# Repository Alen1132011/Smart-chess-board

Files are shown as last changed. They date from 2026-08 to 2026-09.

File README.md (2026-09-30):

# Smart Chess Board

A physical chess board that can detect the position of chess pieces in real time using Hall effect sensors and provide visual feedback through RGB LEDs.

The project combines custom electronics, firmware and a 3D printed enclosure to create a chess board that can understand what is happening on the board without using mechanical switches.

## Budget & SMT Notes

- **Shipping:** Selected the cheapest available shipping method to Bosnia and Herzegovina ($71.75).
- **SMT Assembly:** I attempted to use Economic SMT Assembly to minimize costs, but JLCPCB automatically forces a switch to **Standard SMT Assembly** when incorporating WS2812B addressable LEDs.
- **Self-Funded Components:** To keep the requested grant minimal, I will personally cover all additional hardware costs (ESP32 controller board, magnets, and 3D printing materials for the enclosure).

## Current Status

The PCB design is complete and the first board is being prepared for production and assembly.

The project is still in development. Some features described below are planned and will be added as the hardware and firmware develop.

Once I assemble and test the first board, I will add more information to this repository, including photos, test results and a much more detailed assembly guide.

## Features

* Real-time piece detection using Hall effect sensors
* 128 Hall effect sensors
* RGB lighting under the chess squares
* Custom PCB designed specifically for the board
* Magnetic chess pieces using neodymium magnets
* Firmware developed for the board
* Planned Stockfish integration
* Planned connection to online chess platforms

## How It Works

Each chess piece has a small magnet in its base. Hall effect sensors placed underneath the board detect the magnetic field and determine whether a piece is present on a square.

The board uses 128 sensors connected through 74HC165 shift registers. This allows the microcontroller to read a large number of sensors without requiring a separate input pin for every sensor.

RGB LEDs are placed underneath the squares and can be used to show things such as possible moves, selected pieces, warnings and other information.

The main idea is to keep the playing surface completely clean while putting all of the electronics underneath it.

## Hardware

The main components currently used in the design are:

* Custom PCB designed in KiCad
* 128x HAL2041SO Hall effect sensors
* 16x 74HC165 shift registers
* SK6812 / WS2812B RGB LEDs
* 100nF capacitors
* 10kΩ and 330Ω resistors
* Chess pieces with neodymium magnets

The exact components and values may change after the first prototype is assembled and tested.

## Repository Structure

```text
CAD/              3D models and enclosure design
Firmware/         Board firmware
PCB/              KiCad PCB design files
Production/       Manufacturing and production files
Smart chess board Additional project files
README.md         Project documentation
```

## Assembly

The first version of the board has not been fully assembled yet, so the complete assembly guide is not available at the moment.

After I build the first board, I will add a detailed guide covering:

* PCB assembly
* Hall sensor placement
* LED installation
* Wiring and power
* Magnet placement in the chess pieces
* Firmware installation
* Initial testing and calibration
* Common problems and fixes

I want the guide to be based on the actual first build rather than documenting steps that have not been tested yet.

## Future Plans

The project is still being developed, and more features will be added after the first working board is finished.

Some of the planned improvements include:

* Stockfish integration
* Better move detection and validation
* More RGB lighting effects
* Online chess integration
* Calibration tools
* Improved enclosure
* More detailed documentation

The first assembled board will be an important milestone because it will show which parts of the current design work as expected and which parts need to be improved.

## Libraries and Tools

* KiCad
* PlatformIO
* FastLED
* Stockfish
  
 ## Project Renders & Schematics

chess board_fixed




## Project Status

PCB design: Complete
CAD design: In progress
Firmware: In progress
First board assembly: Upcoming
Detailed assembly guide: Coming after the first build

This project is being developed step by step. The documentation will be updated as the physical board is built, tested and improved.

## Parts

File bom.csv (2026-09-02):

Item | Description | Quantity | Unit Price (USD) | Total Price (USD) | Link
Bare PCBs | JLCPCB 5pcs Custom Boards (Y11-8263520A) | 1 | 23.50 | 23.50 | https://jlcpcb.com
SMT Stencil | JLCPCB SMT Stainless Steel Stencil (100x100mm) | 1 | 3.07 | 3.07 | https://jlcpcb.com
JLCPCB Shipping | Express shipping for PCB & Stencil to BiH | 1 | 43.38 | 43.38 | https://jlcpcb.com
WS2812B LEDs | LCSC C114586 RGB LEDs (100pcs pack) | 100 | 0.0834 | 8.34 | https://www.lcsc.com/product-detail/C114586.html
A3144 Hall Sensors | LCSC C18221462 SOT-23 Hall Effect Sensors (100pcs pack) | 100 | 0.1159 | 11.59 | https://www.lcsc.com/product-detail/C18221462.html
74HC165 ICs | LCSC C5613 SOIC-16 Shift Registers (10pcs pack) | 10 | 0.1171 | 1.17 | https://www.lcsc.com/product-detail/C5613.html
0805 Capacitors 100nF | LCSC C1591 SMD Capacitors (100pcs pack) | 100 | 0.0108 | 1.08 | https://www.lcsc.com/product-detail/C1591.html
0805 Resistors 10k | LCSC C98220 SMD Resistors (100pcs pack) | 100 | 0.0036 | 0.36 | https://www.lcsc.com/product-detail/C98220.html
LCSC Shipping & Discount | Singapore Post shipping ($12.50) minus discount (-$0.61) | 1 | 11.89 | 11.89 | https://www.lcsc.com
ESP32 DevKit | ESP32-WROOM-32D 30-Pin Board | 1 | 3.50 | 3.50 | https://www.aliexpress.com/item/1005005704190069.html
AliExpress ESP32 Shipping | Shipping for ESP32 board to BiH (11.97 BAM) | 1 | 6.70 | 6.70 | https://www.aliexpress.com/item/1005005704190069.html
Type-C Mini Hot Plate | Mini Hot Plate tool for SMT reflow assembly | 1 | 10.00 | 10.00 | https://www.aliexpress.com/item/1005010119785278.html
Grand Total |  |  |  | 125.19

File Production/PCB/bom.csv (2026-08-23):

Reference | Qty | Value | DNP | Exclude from BOM | Exclude from Board | Footprint | Datasheet
A1 | 1 | Arduino_Nano_Every |  |  |  | Module:Arduino_Nano | https://content.arduino.cc/assets/NANOEveryV3.0_sch.pdf
C1,C2,C3,C4,C5,C6,C7,C8,C9,C10,C11,C12,C13,C14,C15,C16,C17,C18,C19,C20,C21,C22,C23,C24,C25,C26,C27,C28,C29,C30,C31,C32,C33,C34,C35,C36,C37,C38,C39,C40,C41,C42,C43,C44,C45,C46,C47,C48,C49,C50,C51,C52,C53,C54,C55,C56,C57,C58,C59,C60,C61,C62,C63,C64 | 64 | 100nF |  |  |  | Capacitor_SMD:C_0805_2012Metric
D1,D2,D3,D4,D5,D6,D7,D8,D9,D10,D11,D12,D13,D14,D15,D16,D17,D18,D19,D20,D21,D22,D23,D24,D25,D26,D27,D28,D29,D30,D31,D32,D33,D34,D35,D36,D37,D38,D39,D40,D41,D42,D43,D44,D45,D46,D47,D48,D49,D50,D51,D52,D53,D54,D55,D56,D57,D58,D59,D60,D61,D62,D63,D64 | 64 | WS2812B |  |  |  | LED_SMD:LED_WS2812B_PLCC4_5.0x5.0mm_P3.2mm | https://cdn-shop.adafruit.com/datasheets/WS2812B.pdf
R1,R3,R4,R5,R6,R7,R8,R9,R10,R11,R12,R13,R14,R15,R16,R17,R18,R19,R20,R21,R22,R23,R24,R25,R26,R27,R28,R29,R30,R31,R32,R33,R34,R35,R36,R37,R38,R39,R40,R41,R42,R43,R44,R45,R46,R47,R48,R49,R50,R51,R52,R53,R54,R55,R56,R57,R58,R59,R60,R61,R62,R63,R64,R65 | 64 | 10k |  |  |  | Resistor_SMD:R_0805_2012Metric
R2 | 1 | 330Ω |  |  |  | Resistor_SMD:R_0805_2012Metric
U1,U3,U4,U5,U6,U7,U8,U9,U11,U12,U13,U14,U15,U16,U17,U18,U20,U21,U22,U23,U24,U25,U26,U27,U29,U30,U31,U32,U33,U34,U35,U36,U38,U39,U40,U41,U42,U43,U44,U45,U47,U48,U49,U50,U51,U52,U53,U54,U56,U57,U58,U59,U60,U61,U62,U63,U65,U66,U67,U68,U69,U70,U71,U72 | 64 | A1104xLH |  |  |  | Package_TO_SOT_SMD:SOT-23W | https://www.allegromicro.com/-/media/files/datasheets/a110x-datasheet.ashx
U2,U10,U19,U28,U37,U46,U55,U64 | 8 | 74HC165 |  |  |  | Package_TO_SOT_SMD:SOT-23W | https://assets.nexperia.com/documents/data-sheet/74HC_HCT165.pdf

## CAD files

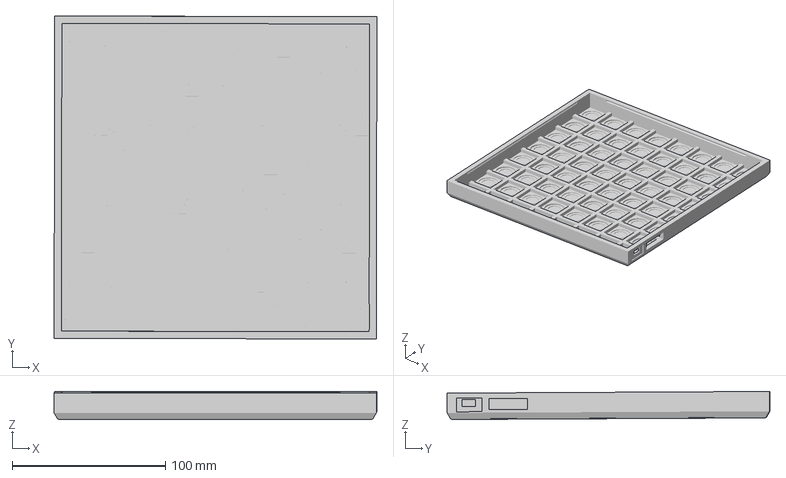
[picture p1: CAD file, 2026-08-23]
Smart chess board/CAD/Chess Board.3mf
210.7 x 210.8 x 18.3 mm

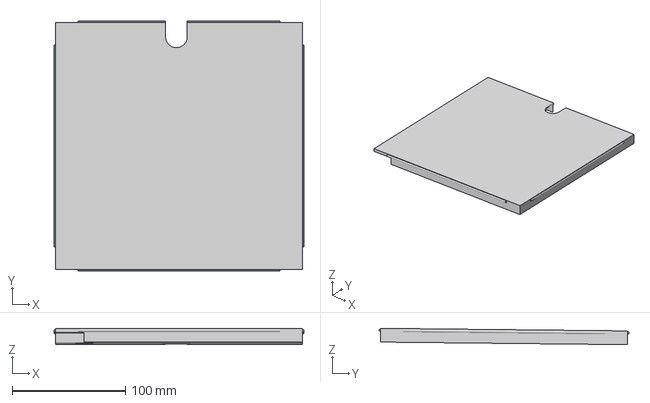
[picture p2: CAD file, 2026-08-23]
Smart chess board/CAD/LID.3mf
220.5 x 220.5 x 14.4 mm

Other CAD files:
CAD/Chess board and lid_.step
PCB/chessboard.step
Production/CAD/Chess board and lid_.step
Smart chess board/PCB/chessboard.step

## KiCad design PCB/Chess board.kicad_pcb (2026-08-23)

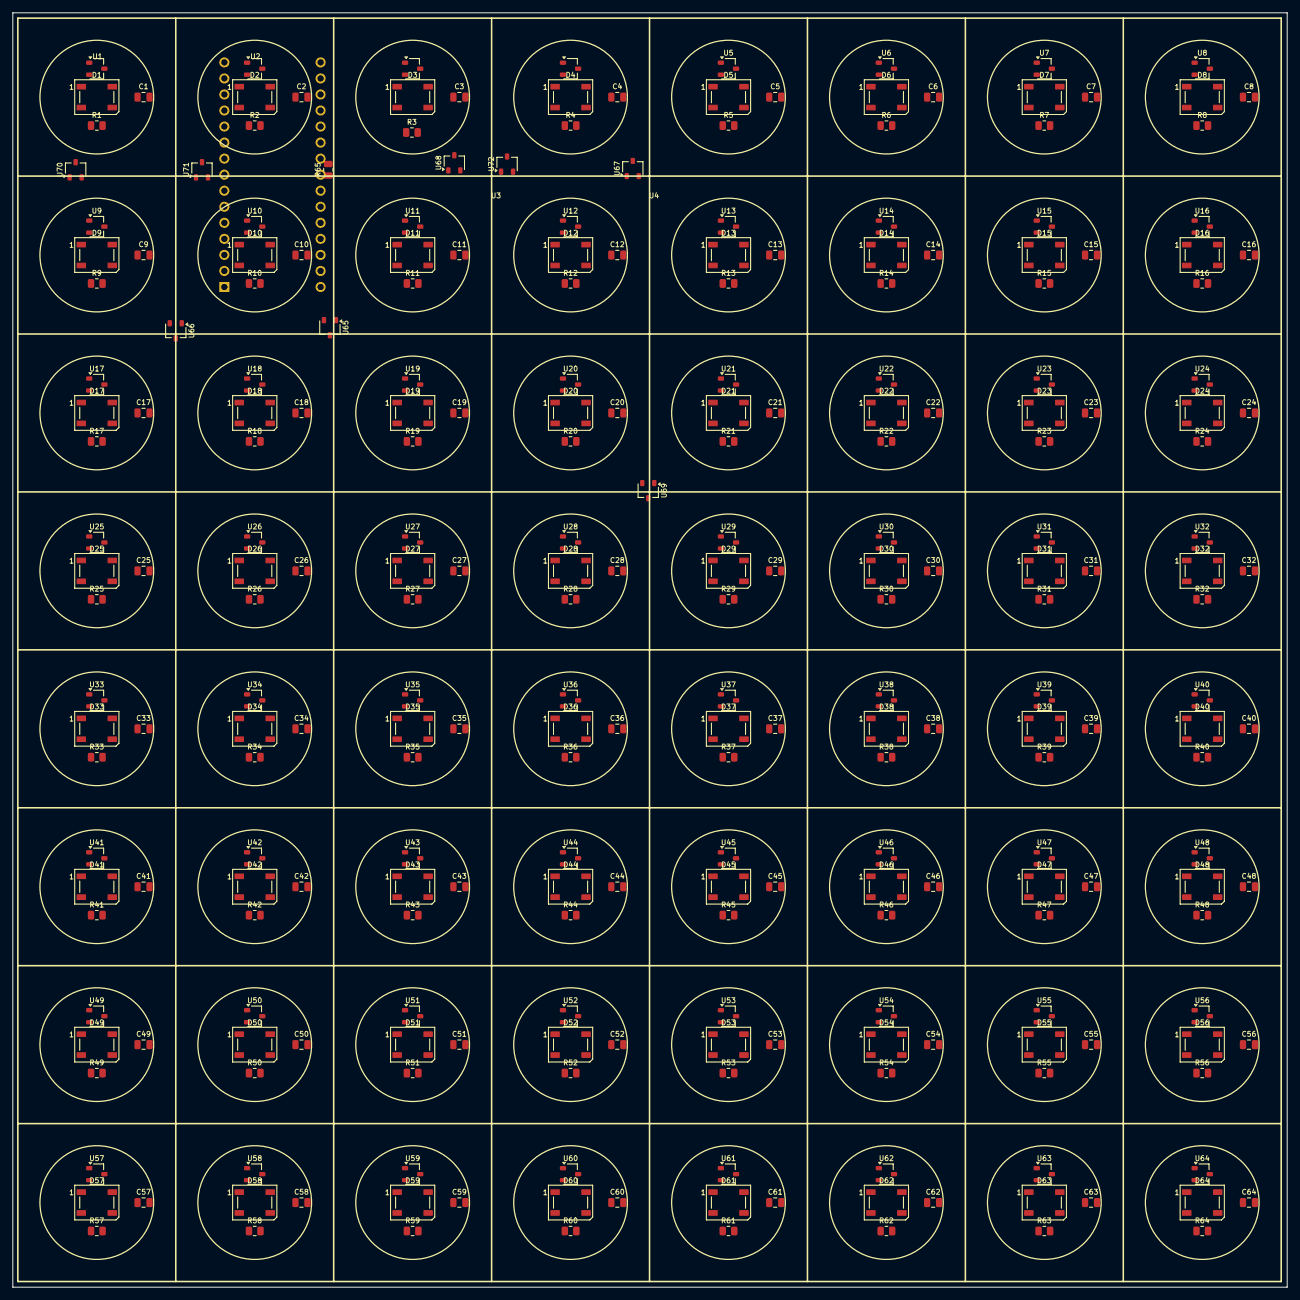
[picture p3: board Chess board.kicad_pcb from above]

Board: 2 copper layers, 201.8 x 201.8 mm, 266 parts (1 on the bottom side), 132 nets, no tracks yet.

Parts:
A1: Arduino_Nano_Every; Arduino_Nano
C1, C2, C3, C4, C5, C6, C7, C8, C9, C10, C11, C12, C13, C14, C15, C16, C17, C18, C19, C20, C21, C22, C23, C24, C25, C26, C27, C28, C29, C30, C31, C32, C33, C34, C35, C36, C37, C38, C39, C40, C41, C42, C43, C44, C45, C46, C47, C48, C49, C50, C51, C52, C53, C54, C55, C56, C57, C58, C59, C60, C61, C62, C63, C64: 100nF; C_0805_2012Metric
D1, D2, D3, D4, D5, D6, D7, D8, D9, D10, D11, D12, D13, D14, D15, D16, D17, D18, D19, D20, D21, D22, D23, D24, D25, D26, D27, D28, D29, D30, D31, D32, D33, D34, D35, D36, D37, D38, D39, D40, D41, D42, D43, D44, D45, D46, D47, D48, D49, D50, D51, D52, D53, D54, D55, D56, D57, D58, D59, D60, D61, D62, D63, D64: WS2812B; LED_WS2812B_PLCC4_5.0x5.0mm_P3.2mm
R1, R3, R4, R5, R6, R7, R8, R9, R10, R11, R12, R13, R14, R15, R16, R17, R18, R19, R20, R21, R22, R23, R24, R25, R26, R27, R28, R29, R30, R31, R32, R33, R34, R35, R36, R37, R38, R39, R40, R41, R42, R43, R44, R45, R46, R47, R48, R49, R50, R51, R52, R53, R54, R55, R56, R57, R58, R59, R60, R61, R62, R63, R64, R65: 10k; R_0805_2012Metric
R2: 330Ω; R_0805_2012Metric
U1, U3, U4, U5, U6, U7, U8, U9, U11, U12, U13, U14, U15, U16, U17, U18, U20, U21, U22, U23, U24, U25, U26, U27, U29, U30, U31, U32, U33, U34, U35, U36, U38, U39, U40, U41, U42, U43, U44, U45, U47, U48, U49, U50, U51, U52, U53, U54, U56, U57, U58, U59, U60, U61, U62, U63, U65, U66, U67, U68, U69, U70, U71, U72: A1104xLH; SOT-23W
U2, U10, U19, U28, U37, U46, U55, U64: 74HC165; SOT-23W

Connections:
+5V: A1.27 (+5V), C1.2, C2.2, C3.2, C4.2, C5.2, C6.2, C7.2, C8.2, C9.2, C10.2, C11.2, C12.2, C13.2, C14.2, C15.2, C16.2, C17.2, C18.2, C19.2, C20.2, C21.2, C22.2, C23.2, C24.2, C25.2, C26.2, C27.2, C28.2, C29.2, C30.2, C31.2, C32.2, C33.2, C34.2, C35.2, C36.2, C37.2, C38.2, C39.2, C40.2, C41.2, C42.2, C43.2, C44.2, C45.2, C46.2, C47.2, C48.2, C49.2, C50.2, C51.2, C52.2, C53.2, C54.2, C55.2, C56.2, C57.2, C58.2, C59.2, C60.2, C61.2, C62.2, C63.2, C64.2, D1.1 (VDD), D2.1 (VDD), D3.1 (VDD), D4.1 (VDD), D5.1 (VDD), D6.1 (VDD), D7.1 (VDD), D8.1 (VDD), D9.1 (VDD), D10.1 (VDD), D11.1 (VDD), D12.1 (VDD), D13.1 (VDD), D14.1 (VDD), D15.1 (VDD), D16.1 (VDD), D17.1 (VDD), D18.1 (VDD), D19.1 (VDD), D20.1 (VDD), D21.1 (VDD), D22.1 (VDD), D23.1 (VDD), D24.1 (VDD), D25.1 (VDD), D26.1 (VDD), D27.1 (VDD), D28.1 (VDD), D29.1 (VDD), D30.1 (VDD), D31.1 (VDD), D32.1 (VDD), D33.1 (VDD), D34.1 (VDD), D35.1 (VDD), D36.1 (VDD), D37.1 (VDD), D38.1 (VDD), D39.1 (VDD), D40.1 (VDD), D41.1 (VDD), D42.1 (VDD), D43.1 (VDD), D44.1 (VDD), D45.1 (VDD), D46.1 (VDD), D47.1 (VDD), D48.1 (VDD), D49.1 (VDD), D50.1 (VDD), D51.1 (VDD), D52.1 (VDD), D53.1 (VDD), D54.1 (VDD), D55.1 (VDD), D56.1 (VDD), D57.1 (VDD), D58.1 (VDD), D59.1 (VDD), D60.1 (VDD), D61.1 (VDD), D62.1 (VDD), D63.1 (VDD), D64.1 (VDD), R1.1, R3.1, R4.1, R5.1, R6.1, R7.1, R8.1, R9.1, R10.1, R11.1, R12.1, R13.1, R14.1, R15.1, R16.1, R17.1, R18.1, R19.1, R20.1, R21.1, R22.1, R23.1, R24.1, R25.1, R26.1, R27.1, R28.1, R29.1, R30.1, R31.1, R32.1, R33.1, R34.1, R35.1, R36.1, R37.1, R38.1, R39.1, R40.1, R41.1, R42.1, R43.1, R44.1, R45.1, R46.1, R47.1, R48.1, R49.1, R50.1, R51.1, R52.1, R53.1, R54.1, R55.1, R56.1, R57.1, R58.1, R59.1, R60.1, R61.1, R62.1, R63.1, R64.1, R65.1, U1.1 (V_{CC}), U3.1 (V_{CC}), U4.1 (V_{CC}), U5.1 (V_{CC}), U6.1 (V_{CC}), U7.1 (V_{CC}), U8.1 (V_{CC}), U9.1 (V_{CC}), U11.1 (V_{CC}), U12.1 (V_{CC}), U13.1 (V_{CC}), U14.1 (V_{CC}), U15.1 (V_{CC}), U16.1 (V_{CC}), U17.1 (V_{CC}), U18.1 (V_{CC}), U20.1 (V_{CC}), U21.1 (V_{CC}), U22.1 (V_{CC}), U23.1 (V_{CC}), U24.1 (V_{CC}), U25.1 (V_{CC}), U26.1 (V_{CC}), U27.1 (V_{CC}), U29.1 (V_{CC}), U30.1 (V_{CC}), U31.1 (V_{CC}), U32.1 (V_{CC}), U33.1 (V_{CC}), U34.1 (V_{CC}), U35.1 (V_{CC}), U36.1 (V_{CC}), U38.1 (V_{CC}), U39.1 (V_{CC}), U40.1 (V_{CC}), U41.1 (V_{CC}), U42.1 (V_{CC}), U43.1 (V_{CC}), U44.1 (V_{CC}), U45.1 (V_{CC}), U47.1 (V_{CC}), U48.1 (V_{CC}), U49.1 (V_{CC}), U50.1 (V_{CC}), U51.1 (V_{CC}), U52.1 (V_{CC}), U53.1 (V_{CC}), U54.1 (V_{CC}), U56.1 (V_{CC}), U57.1 (V_{CC}), U58.1 (V_{CC}), U59.1 (V_{CC}), U60.1 (V_{CC}), U61.1 (V_{CC}), U62.1 (V_{CC}), U63.1 (V_{CC}), U65.1 (V_{CC}), U66.1 (V_{CC}), U67.1 (V_{CC}), U68.1 (V_{CC}), U69.1 (V_{CC}), U70.1 (V_{CC}), U71.1 (V_{CC}), U72.1 (V_{CC})
/S0: R1.2, U1.2 (V_{OUT})
/S1: R3.2, U3.2 (V_{OUT})
/S2: R4.2, U4.2 (V_{OUT})
/S3: R5.2, U5.2 (V_{OUT})
/S4: R6.2, U2.3 (D4), U6.2 (V_{OUT})
/S5: R7.2, U7.2 (V_{OUT})
/S6: R8.2, U8.2 (V_{OUT})
/S7: R9.2, U9.2 (V_{OUT})
/S8: R11.2, U11.2 (V_{OUT})
/S9: R10.2, U12.2 (V_{OUT})
/S10: R12.2, U13.2 (V_{OUT})
/S11: R13.2, U14.2 (V_{OUT})
/S12: R14.2, U10.3 (D4), U15.2 (V_{OUT})
/S13: R15.2, U16.2 (V_{OUT})
/S14: R16.2, U17.2 (V_{OUT})
/S15: R17.2, U18.2 (V_{OUT})
/S16: R18.2, U20.2 (V_{OUT})
/S17: R19.2, U21.2 (V_{OUT})
/S18: R20.2, U22.2 (V_{OUT})
/S19: R21.2, U23.2 (V_{OUT})
/S20: R22.2, U19.3 (D4), U24.2 (V_{OUT})
/S21: R23.2, U25.2 (V_{OUT})
/S22: R24.2, U26.2 (V_{OUT})
/S23: R25.2, U27.2 (V_{OUT})
/S24: R26.2, U29.2 (V_{OUT})
/S25: R27.2, U30.2 (V_{OUT})
/S26: R28.2, U31.2 (V_{OUT})
/S27: R29.2, U32.2 (V_{OUT})
/S28: R30.2, U28.3 (D4), U33.2 (V_{OUT})
/S29: R31.2, U34.2 (V_{OUT})
/S30: R32.2, U35.2 (V_{OUT})
/S31: R33.2, U36.2 (V_{OUT})
/S32: R34.2, U38.2 (V_{OUT})
/S33: R35.2, U39.2 (V_{OUT})
/S34: R36.2, U40.2 (V_{OUT})
/S35: R37.2, U41.2 (V_{OUT})
/S36: R38.2, U37.3 (D4), U42.2 (V_{OUT})
/S37: R39.2, U43.2 (V_{OUT})
/S38: R40.2, U44.2 (V_{OUT})
/S39: R41.2, U45.2 (V_{OUT})
/S40: R42.2, U47.2 (V_{OUT})
/S41: R43.2, U48.2 (V_{OUT})
/S42: R44.2, U49.2 (V_{OUT})
/S43: R45.2, U50.2 (V_{OUT})
/S44: R46.2, U46.3 (D4), U51.2 (V_{OUT})
/S45: R47.2, U52.2 (V_{OUT})
/S46: R48.2, U53.2 (V_{OUT})
/S47: R49.2, U54.2 (V_{OUT})
/S48: R50.2, U56.2 (V_{OUT})
/S49: R51.2, U57.2 (V_{OUT})
/S50: R52.2, U58.2 (V_{OUT})
/S51: R53.2, U59.2 (V_{OUT})
/S52: R54.2, U55.3 (D4), U60.2 (V_{OUT})
/S53: R55.2, U61.2 (V_{OUT})
/S54: R56.2, U62.2 (V_{OUT})
/S55: R57.2, U63.2 (V_{OUT})
/S56: R58.2, U65.2 (V_{OUT})
/S57: R59.2, U66.2 (V_{OUT})
/S58: R60.2, U67.2 (V_{OUT})
/S59: R61.2, U68.2 (V_{OUT})
/S60: R62.2, U64.3 (D4), U69.2 (V_{OUT})
/S61: R63.2, U70.2 (V_{OUT})
/S62: R64.2, U71.2 (V_{OUT})
/S63: R65.2, U72.2 (V_{OUT})
GND: A1.4 (GND), A1.6 (D3), A1.29 (GND), C1.1, C2.1, C3.1, C4.1, C5.1, C6.1, C7.1, C8.1, C9.1, C10.1, C11.1, C12.1, C13.1, C14.1, C15.1, C16.1, C17.1, C18.1, C19.1, C20.1, C21.1, C22.1, C23.1, C24.1, C25.1, C26.1, C27.1, C28.1, C29.1, C30.1, C31.1, C32.1, C33.1, C34.1, C35.1, C36.1, C37.1, C38.1, C39.1, C40.1, C41.1, C42.1, C43.1, C44.1, C45.1, C46.1, C47.1, C48.1, C49.1, C50.1, C51.1, C52.1, C53.1, C54.1, C55.1, C56.1, C57.1, C58.1, C59.1, C60.1, C61.1, C62.1, C63.1, C64.1, D1.3 (VSS), D2.3 (VSS), D3.3 (VSS), D4.3 (VSS), D5.3 (VSS), D6.3 (VSS), D7.3 (VSS), D8.3 (VSS), D9.3 (VSS), D10.3 (VSS), D11.3 (VSS), D12.3 (VSS), D13.3 (VSS), D14.3 (VSS), D15.3 (VSS), D16.3 (VSS), D17.3 (VSS), D18.3 (VSS), D19.3 (VSS), D20.3 (VSS), D21.3 (VSS), D22.3 (VSS), D23.3 (VSS), D24.3 (VSS), D25.3 (VSS), D26.3 (VSS), D27.3 (VSS), D28.3 (VSS), D29.3 (VSS), D30.3 (VSS), D31.3 (VSS), D32.3 (VSS), D33.3 (VSS), D34.3 (VSS), D35.3 (VSS), D36.3 (VSS), D37.3 (VSS), D38.3 (VSS), D39.3 (VSS), D40.3 (VSS), D41.3 (VSS), D42.3 (VSS), D43.3 (VSS), D44.3 (VSS), D45.3 (VSS), D46.3 (VSS), D47.3 (VSS), D48.3 (VSS), D49.3 (VSS), D50.3 (VSS), D51.3 (VSS), D52.3 (VSS), D53.3 (VSS), D54.3 (VSS), D55.3 (VSS), D56.3 (VSS), D57.3 (VSS), D58.3 (VSS), D59.3 (VSS), D60.3 (VSS), D61.3 (VSS), D62.3 (VSS), D63.3 (VSS), D64.2 (DOUT), D64.3 (VSS), U1.3 (GND), U2.1 (~PL), U3.3 (GND), U4.3 (GND), U5.3 (GND), U6.3 (GND), U7.3 (GND), U8.3 (GND), U9.3 (GND), U10.1 (~PL), U11.3 (GND), U12.3 (GND), U13.3 (GND), U14.3 (GND), U15.3 (GND), U16.3 (GND), U17.3 (GND), U18.3 (GND), U19.1 (~PL), U20.3 (GND), U21.3 (GND), U22.3 (GND), U23.3 (GND), U24.3 (GND), U25.3 (GND), U26.3 (GND), U27.3 (GND), U28.1 (~PL), U29.3 (GND), U30.3 (GND), U31.3 (GND), U32.3 (GND), U33.3 (GND), U34.3 (GND), U35.3 (GND), U36.3 (GND), U37.1 (~PL), U38.3 (GND), U39.3 (GND), U40.3 (GND), U41.3 (GND), U42.3 (GND), U43.3 (GND), U44.3 (GND), U45.3 (GND), U46.1 (~PL), U47.3 (GND), U48.3 (GND), U49.3 (GND), U50.3 (GND), U51.3 (GND), U52.3 (GND), U53.3 (GND), U54.3 (GND), U55.1 (~PL), U56.3 (GND), U57.3 (GND), U58.3 (GND), U59.3 (GND), U60.3 (GND), U61.3 (GND), U62.3 (GND), U63.3 (GND), U64.1 (~PL), U65.3 (GND), U66.3 (GND), U67.3 (GND), U68.3 (GND), U69.3 (GND), U70.3 (GND), U71.3 (GND), U72.3 (GND)
unnamed: A1.5 (D2), U2.2 (CP), U10.2 (CP), U19.2 (CP), U28.2 (CP), U37.2 (CP), U46.2 (CP), U55.2 (CP), U64.2 (CP)
unnamed: A1.9 (D6), R2.2
unnamed: D1.4 (DIN), R2.1
unnamed: D1.2 (DOUT), D2.4 (DIN)
unnamed: D2.2 (DOUT), D3.4 (DIN)
unnamed: D3.2 (DOUT), D4.4 (DIN)
unnamed: D4.2 (DOUT), D5.4 (DIN)
unnamed: D5.2 (DOUT), D6.4 (DIN)
unnamed: D6.2 (DOUT), D7.4 (DIN)
unnamed: D7.2 (DOUT), D8.4 (DIN)
unnamed: D8.2 (DOUT), D9.4 (DIN)
unnamed: D9.2 (DOUT), D10.4 (DIN)
unnamed: D10.2 (DOUT), D11.4 (DIN)
unnamed: D11.2 (DOUT), D12.4 (DIN)
unnamed: D12.2 (DOUT), D13.4 (DIN)
unnamed: D13.2 (DOUT), D14.4 (DIN)
unnamed: D14.2 (DOUT), D15.4 (DIN)
unnamed: D15.2 (DOUT), D16.4 (DIN)
unnamed: D16.2 (DOUT), D17.4 (DIN)
unnamed: D17.2 (DOUT), D18.4 (DIN)
unnamed: D18.2 (DOUT), D19.4 (DIN)
unnamed: D19.2 (DOUT), D20.4 (DIN)
unnamed: D20.2 (DOUT), D21.4 (DIN)
unnamed: D21.2 (DOUT), D22.4 (DIN)
unnamed: D22.2 (DOUT), D23.4 (DIN)
unnamed: D23.2 (DOUT), D24.4 (DIN)
unnamed: D24.2 (DOUT), D25.4 (DIN)
unnamed: D25.2 (DOUT), D26.4 (DIN)
unnamed: D26.2 (DOUT), D27.4 (DIN)
unnamed: D27.2 (DOUT), D28.4 (DIN)
unnamed: D28.2 (DOUT), D29.4 (DIN)
unnamed: D29.2 (DOUT), D30.4 (DIN)
unnamed: D30.2 (DOUT), D31.4 (DIN)
unnamed: D31.2 (DOUT), D32.4 (DIN)
unnamed: D32.2 (DOUT), D33.4 (DIN)
unnamed: D33.2 (DOUT), D34.4 (DIN)
unnamed: D34.2 (DOUT), D35.4 (DIN)
unnamed: D35.2 (DOUT), D36.4 (DIN)
unnamed: D36.2 (DOUT), D37.4 (DIN)
unnamed: D37.2 (DOUT), D38.4 (DIN)
unnamed: D38.2 (DOUT), D39.4 (DIN)
unnamed: D39.2 (DOUT), D40.4 (DIN)
unnamed: D40.2 (DOUT), D41.4 (DIN)
unnamed: D41.2 (DOUT), D42.4 (DIN)
unnamed: D42.2 (DOUT), D43.4 (DIN)
unnamed: D43.2 (DOUT), D44.4 (DIN)
unnamed: D44.2 (DOUT), D45.4 (DIN)
unnamed: D45.2 (DOUT), D46.4 (DIN)
unnamed: D46.2 (DOUT), D47.4 (DIN)
unnamed: D47.2 (DOUT), D48.4 (DIN)
unnamed: D48.2 (DOUT), D49.4 (DIN)
unnamed: D49.2 (DOUT), D50.4 (DIN)
unnamed: D50.2 (DOUT), D51.4 (DIN)
unnamed: D51.2 (DOUT), D52.4 (DIN)
unnamed: D52.2 (DOUT), D53.4 (DIN)
unnamed: D53.2 (DOUT), D54.4 (DIN)
unnamed: D54.2 (DOUT), D55.4 (DIN)
unnamed: D55.2 (DOUT), D56.4 (DIN)
unnamed: D56.2 (DOUT), D57.4 (DIN)
unnamed: D57.2 (DOUT), D58.4 (DIN)
unnamed: D58.2 (DOUT), D59.4 (DIN)
unnamed: D59.2 (DOUT), D60.4 (DIN)
unnamed: D60.2 (DOUT), D61.4 (DIN)
unnamed: D61.2 (DOUT), D62.4 (DIN)
unnamed: D62.2 (DOUT), D63.4 (DIN)
unnamed: D63.2 (DOUT), D64.4 (DIN)

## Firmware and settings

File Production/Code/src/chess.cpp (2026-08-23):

#include <Arduino.h>
#include <FastLED.h>

void calibratesensors();
void initializeboard();
bool isenpassantpossible(int from, int to);

const int ledPin = 3;
const int latchPin = 2;
const int clockPin = 4;
const int dataPin = 5;
const int numLEDs = 64;

CRGB leds[numLEDs];
bool sensorstate[numLEDs];
bool lastsensorstate[numLEDs];
bool sensorbaseline[numLEDs];
bool sensorinverted = false;

bool whitekinghasmoved = false;
bool whiterookkingsidehasmoved = false;
bool whiterookqueensidehasmoved = false;
bool blackkinghasmoved = false;
bool blackrookkingsidehasmoved = false;
bool blackrookqueensidehasmoved = false;
int enpassanttarget = -1;

enum PieceType {
  EMPTY,
  WP,
  WN,
  WB,
  WR,
  WQ,
  WK,
  BP,
  BN,
  BB,
  BR,
  BQ,
  BK
};

PieceType board[64];
bool whiteTurn = true;
int selectedsquare = -1;

PieceType getpieceat(int square) {
  if (square < 0 || square >= 64) return EMPTY;
  return board[square];
}

bool iswhitepiece(PieceType piece) {
  return piece == WP || piece == WN || piece == WB ||
         piece == WR || piece == WQ || piece == WK;
}

bool isblackpiece(PieceType piece) {
  return piece == BP || piece == BN || piece == BB ||
         piece == BR || piece == BQ || piece == BK;
}

bool isoccupied(int square) {
  return getpieceat(square) != EMPTY;
}

bool readsensorvalue(int index) {
  bool raw = (digitalRead(dataPin) == HIGH);
  return sensorinverted ? !raw : raw;
}

bool ispathclear(int from, int to) {
  int dx = (to % 8) - (from % 8);
  int dy = (to / 8) - (from / 8);
  int stepx = 0;
  int stepy = 0;

  if (dx != 0) stepx = dx > 0 ? 1 : -1;
  if (dy != 0) stepy = dy > 0 ? 1 : -1;

  int steps = max(abs(dx), abs(dy));

  for (int i = 1; i < steps; i++) {
    int x = (from % 8) + stepx * i;
    int y = (from / 8) + stepy * i;
    int square = y * 8 + x;

    if (isoccupied(square)) return false;
  }

  return true;
}

bool isknightmove(int from, int to) {
  int dx = abs((to % 8) - (from % 8));
  int dy = abs((to / 8) - (from / 8));

  return (dx == 2 && dy == 1) || (dx == 1 && dy == 2);
}

bool ispawnmove(int from, int to, bool iswhite) {
  int dx = (to % 8) - (from % 8);
  int dy = (to / 8) - (from / 8);

  if (iswhite) {
    if (dx == 0) {
      if (dy == -1 && !isoccupied(to)) return true;

      if (dy == -2 &&
          from / 8 == 6 &&
          !isoccupied(to) &&
          !isoccupied(from - 8)) {
        return true;
      }
    }

    if (abs(dx) == 1 && dy == -1) {
      if (isoccupied(to) && isblackpiece(getpieceat(to))) return true;
      if (isenpassantpossible(from, to)) return true;
    }
  } else {
    if (dx == 0) {
      if (dy == 1 && !isoccupied(to)) return true;

      if (dy == 2 &&
          from / 8 == 1 &&
          !isoccupied(to) &&
          !isoccupied(from + 8)) {
        return true;
      }
    }

    if (abs(dx) == 1 && dy == 1) {
      if (isoccupied(to) && iswhitepiece(getpieceat(to))) return true;
      if (isenpassantpossible(from, to)) return true;
    }
  }

  return false;
}

bool iskingmove(int from, int to) {
  int dx = abs((to % 8) - (from % 8));
  int dy = abs((to / 8) - (from / 8));

  return dx <= 1 && dy <= 1;
}

bool issquareunderattack(int square, bool bywhite) {
  for (int i = 0; i < 64; i++) {
    PieceType piece = getpieceat(i);

    if (piece == EMPTY) continue;

    bool pieceiswhite = iswhitepiece(piece);

    if (pieceiswhite != bywhite) continue;

    switch (piece) {
      case EMPTY:
        break;

      case WP:
        if (abs((i % 8) - (square % 8)) == 1 &&
            (square / 8) == (i / 8) - 1) {
          return true;
        }
        break;

      case BP:
        if (abs((i % 8) - (square % 8)) == 1 &&
            (square / 8) == (i / 8) + 1) {
          return true;
        }
        break;

      case WN:
      case BN:
        if (isknightmove(i, square)) return true;
        break;

      case WB:
      case BB:
        if (abs((square % 8) - (i % 8)) ==
                abs((square / 8) - (i / 8)) &&
            ispathclear(i, square)) {
          return true;
        }
        break;

      case WR:
      case BR:
        if (((square % 8) == (i % 8) ||
             (square / 8) == (i / 8)) &&
            ispathclear(i, square)) {
          return true;
        }
        break;

      case WQ:
      case BQ:
        if ((((square % 8) == (i % 8) ||
              (square / 8) == (i / 8)) ||
             abs((square % 8) - (i % 8)) ==
                 abs((square / 8) - (i / 8))) &&
            ispathclear(i, square)) {
          return true;
        }
        break;

      case WK:
      case BK:
        if (iskingmove(i, square)) return true;
        break;
    }
  }

  return false;
}

bool isincheck(bool whiteTurn) {
  int kingsquare = -1;

  for (int i = 0; i < 64; i++) {
    PieceType piece = getpieceat(i);

    if (piece == (whiteTurn ? WK : BK)) {
      kingsquare = i;
      break;
    }
  }

  if (kingsquare == -1) return false;

  return issquareunderattack(kingsquare, !whiteTurn);
}

bool isenpassantpossible(int from, int to) {
  if (enpassanttarget == -1) return false;

  PieceType piece = getpieceat(from);
  bool iswhite = iswhitepiece(piece);

  if (piece != WP && piece != BP) return false;

  if (abs((from % 8) - (to % 8)) != 1) return false;

  int pawardirection = iswhite ? -1 : 1;

  if ((to / 8) - (from / 8) != pawardirection) return false;

  if (to != enpassanttarget) return false;

  int passedpawnsquare =
      (enpassanttarget / 8) * 8 + (from % 8);

  PieceType passedpawn = getpieceat(passedpawnsquare);

  if (iswhite) {
    return passedpawn == BP;
  }

  return passedpawn == WP;
}

bool wouldmovecausecheck(int from, int to, bool whiteTurn) {
  PieceType captured = board[to];
  PieceType mover = board[from];

  bool enpassant = isenpassantpossible(from, to);
  int capturedpawnsquare = -1;
  PieceType enpassantcaptured = EMPTY;

  if (enpassant) {
    capturedpawnsquare =
        (enpassanttarget / 8) * 8 + (from % 8);

    enpassantcaptured = board[capturedpawnsquare];
    board[capturedpawnsquare] = EMPTY;
  }

  board[to] = mover;
  board[from] = EMPTY;

  bool incheck = isincheck(whiteTurn);

  board[from] = mover;
  board[to] = captured;

  if (enpassant) {
    board[capturedpawnsquare] = enpassantcaptured;
  }

  return incheck;
}

bool iscastlingpossible(
    int kingfrom,
    int rookfrom,
    int kingto,
    bool whiteside) {

  if (whiteside) {
    if (whitekinghasmoved) return false;

    if (rookfrom == 0 && whiterookqueensidehasmoved)
      return false;

    if (rookfrom == 7 && whiterookkingsidehasmoved)
      return false;

    if (board[rookfrom] != WR) return false;
  } else {
    if (blackkinghasmoved) return false;

    if (rookfrom == 0 && blackrookqueensidehasmoved)
      return false;

    if (rookfrom == 7 && blackrookkingsidehasmoved)
      return false;

    if (board[rookfrom] != BR) return false;
  }

  if (isincheck(whiteside)) return false;

  int step = (kingto > kingfrom) ? 1 : -1;

  for (int sq = kingfrom + step; sq != kingto; sq += step) {
    if (isoccupied(sq)) return false;

    if (wouldmovecausecheck(kingfrom, sq, whiteside))
      return false;
  }

  return !wouldmovecausecheck(kingfrom, kingto, whiteside);
}

bool ispawnpromotion(int from, int to, PieceType piece) {
  if (piece != WP && piece != BP) return false;

  int torank = to / 8;

  return (iswhitepiece(piece) && torank == 0) ||
         (!iswhitepiece(piece) && torank == 7);
}

bool islegalmove(int from, int to) {
  if (from < 0 || from >= 64 ||
      to < 0 || to >= 64) {
    return false;
  }

  if (from == to) return false;

  PieceType piece = getpieceat(from);

  if (piece == EMPTY) return false;

  bool pieceiswhite = iswhitepiece(piece);

  if ((whiteTurn && !pieceiswhite) ||
      (!whiteTurn && pieceiswhite)) {
    return false;
  }

  if (isoccupied(to) &&
      iswhitepiece(getpieceat(to)) == pieceiswhite) {
    return false;
  }

  switch (piece) {
    case EMPTY:
      return false;

    case WP:
      return ispawnmove(from, to, true) &&
             !wouldmovecausecheck(from, to, true);

    case BP:
      return ispawnmove(from, to, false) &&
             !wouldmovecausecheck(from, to, false);

    case WN:
    case BN:
      return isknightmove(from, to) &&
             !wouldmovecausecheck(from, to, whiteTurn);

    case WB:
    case BB:
      if (!ispathclear(from, to)) return false;

      if (abs((to % 8) - (from % 8)) !=
          abs((to / 8) - (from / 8))) {
        return false;
      }

      return !wouldmovecausecheck(from, to, whiteTurn);

    case WR:
    case BR:
      if (!ispathclear(from, to)) return false;

      if ((from % 8) != (to % 8) &&
          (from / 8) != (to / 8)) {
        return false;
      }

      return !wouldmovecausecheck(from, to, whiteTurn);

    case WQ:
    case BQ: {
      if (!ispathclear(from, to)) return false;

      bool diagonal =
          abs((to % 8) - (from % 8)) ==
          abs((to / 8) - (from / 8));

      bool straight =
          (from % 8) == (to % 8) ||
          (from / 8) == (to / 8);

      if (!(diagonal || straight)) return false;

      return !wouldmovecausecheck(from, to, whiteTurn);
    }

    case WK: {
      int dx = abs((to % 8) - (from % 8));
      int dy = abs((to / 8) - (from / 8));

      if (dx == 2 && dy == 0) {
        if (!whiteTurn) return false;

        return iscastlingpossible(
            from,
            (to > from) ? 7 : 0,
            to,
            true
        );
      }

      if (!iskingmove(from, to)) return false;

      return !wouldmovecausecheck(from, to, whiteTurn);
    }

    case BK: {
      int dx = abs((to % 8) - (from % 8));
      int dy = abs((to / 8) - (from / 8));

      if (dx == 2 && dy == 0) {
        if (whiteTurn) return false;

        return iscastlingpossible(
            from,
            (to > from) ? 7 : 0,
            to,
            false
        );
      }

      if (!iskingmove(from, to)) return false;

      return !wouldmovecausecheck(from, to, whiteTurn);
    }

    default:
      return false;
  }
}

void makemove(int from, int to) {
  if (!islegalmove(from, to)) return;

  PieceType piece = getpieceat(from);
  bool iswhite = iswhitepiece(piece);

  bool enpassant = isenpassantpossible(from, to);

  int capturedpawnsquare = -1;

  if (enpassant) {
    capturedpawnsquare =
        (enpassanttarget / 8) * 8 + (from % 8);
  }

  if (iswhitepiece(piece)) {
    if (piece == WK) {
      whitekinghasmoved = true;
    }

    if (piece == WR) {
      if (from == 0)
        whiterookqueensidehasmoved = true;

      if (from == 7)
        whiterookkingsidehasmoved = true;
    }
  } else {
    if (piece == BK) {
      blackkinghasmoved = true;
    }

    if (piece == BR) {
      if (from == 0)
        blackrookqueensidehasmoved = true;

      if (from == 7)
        blackrookkingsidehasmoved = true;
    }
  }

  if (board[to] == WR) {
    if (to == 0)
      whiterookqueensidehasmoved = true;

    if (to == 7)
      whiterookkingsidehasmoved = true;
  }

  if (board[to] == BR) {
    if (to == 0)
      blackrookqueensidehasmoved = true;

    if (to == 7)
      blackrookkingsidehasmoved = true;
  }

  board[to] = piece;
  board[from] = EMPTY;

  if (ispawnpromotion(from, to, piece)) {
    board[to] = iswhite ? WQ : BQ;
  }

  if (enpassant && capturedpawnsquare >= 0) {
    board[capturedpawnsquare] = EMPTY;
  }

  if (piece == WP || piece == BP) {
    if (abs((to / 8) - (from / 8)) == 2) {
      enpassanttarget = (from + to) / 2;
    } else {
      enpassanttarget = -1;
    }
  } else {
    enpassanttarget = -1;
  }

  if (piece == WK &&
      abs((to % 8) - (from % 8)) == 2) {

    if (to > from) {
      board[5] = board[7];
      board[7] = EMPTY;
    } else {
      board[3] = board[0];
      board[0] = EMPTY;
    }
  }

  if (piece == BK &&
      abs((to % 8) - (from % 8)) == 2) {

    if (to > from) {
      board[61] = board[63];
      board[63] = EMPTY;
    } else {
      board[59] = board[56];
      board[56] = EMPTY;
    }
  }

  whiteTurn = !whiteTurn;
}

void readsensors() {
  digitalWrite(latchPin, LOW);
  delayMicroseconds(5);
  digitalWrite(latchPin, HIGH);

  for (int i = 0; i < numLEDs; i++) {
    sensorstate[i] = readsensorvalue(i);

    digitalWrite(clockPin, HIGH);
    delayMicroseconds(5);
    digitalWrite(clockPin, LOW);
  }
}

void updateleds() {
  for (int i = 0; i < numLEDs; i++) {
    leds[i] = CRGB::Black;
  }

  for (int i = 0; i < numLEDs; i++) {
    PieceType piece = getpieceat(i);

    if (piece == EMPTY) continue;

    if (iswhitepiece(piece)) {
      leds[i] = CRGB::White;
    } else {
      leds[i] = CRGB::Blue;
    }
  }

  if (selectedsquare != -1) {
    leds[selectedsquare] = CRGB::Yellow;
  }
}

void checkformove() {
  static bool piecelifted = false;
  static int liftsquare = -1;

  readsensors();

  bool changed = false;

  for (int i = 0; i < numLEDs; i++) {
    if (sensorstate[i] != lastsensorstate[i]) {
      changed = true;
      lastsensorstate[i] = sensorstate[i];
    }
  }

  if (!changed) return;

  if (!piecelifted) {
    for (int i = 0; i < numLEDs; i++) {
      if (!sensorstate[i] &&
          lastsensorstate[i] &&
          isoccupied(i)) {

        piecelifted = true;
        liftsquare = i;
        selectedsquare = i;

        break;
      }
    }
  } else {
    for (int i = 0; i < numLEDs; i++) {
      if (sensorstate[i] &&
          !lastsensorstate[i]) {

        if (islegalmove(liftsquare, i)) {
          makemove(liftsquare, i);
        }

        piecelifted = false;
        liftsquare = -1;
        selectedsquare = -1;

        break;
      }
    }

    if (piecelifted) {
      for (int i = 0; i < numLEDs; i++) {
        if (sensorstate[i] &&
            liftsquare == i) {

          piecelifted = false;
          liftsquare = -1;
          selectedsquare = -1;

          break;
        }
      }
    }
  }
}

bool ischeckmate() {
  if (!isincheck(whiteTurn)) return false;

  for (int from = 0; from < numLEDs; from++) {
    for (int to = 0; to < numLEDs; to++) {
      if (islegalmove(from, to)) {
        return false;
      }
    }
  }

  return true;
}

bool isstalemate() {
  if (isincheck(whiteTurn)) return false;

  for (int from = 0; from < numLEDs; from++) {
    for (int to = 0; to < numLEDs; to++) {
      if (islegalmove(from, to)) {
        return false;
      }
    }
  }

  return true;
}

void calibratesensors() {
  bool samples[10][64];

  for (int sample = 0; sample < 10; sample++) {
    digitalWrite(latchPin, LOW);
    delayMicroseconds(5);
    digitalWrite(latchPin, HIGH);

    for (int i = 0; i < numLEDs; i++) {
      samples[sample][i] =
          (digitalRead(dataPin) == HIGH);

      digitalWrite(clockPin, HIGH);
      delayMicroseconds(5);
      digitalWrite(clockPin, LOW);
    }

    delay(10);
  }

  for (int i = 0; i < 64; i++) {
    int highcount = 0;

    for (int sample = 0; sample < 10; sample++) {
      if (samples[sample][i]) highcount++;
    }

    sensorbaseline[i] = (highcount >= 5);
  }

  int baselinehigh = 0;

  for (int i = 0; i < 64; i++) {
    if (sensorbaseline[i]) baselinehigh++;
  }

  sensorinverted = (baselinehigh > 32);
}

void initializeboard() {
  for (int i = 0; i < 64; i++) {
    board[i] = EMPTY;
    lastsensorstate[i] = sensorbaseline[i];
  }

  board[0] = BR;
  board[1] = BN;
  board[2] = BB;
  board[3] = BQ;
  board[4] = BK;
  board[5] = BB;
  board[6] = BN;
  board[7] = BR;

  board[8] = BP;
  board[9] = BP;
  board[10] = BP;
  board[11] = BP;
  board[12] = BP;
  board[13] = BP;
  board[14] = BP;
  board[15] = BP;

  board[48] = WP;
  board[49] = WP;
  board[50] = WP;
  board[51] = WP;
  board[52] = WP;
  board[53] = WP;
  board[54] = WP;
  board[55] = WP;

  board[56] = WR;
  board[57] = WN;
  board[58] = WB;
  board[59] = WQ;
  board[60] = WK;
  board[61] = WB;
  board[62] = WN;
  board[63] = WR;

  whitekinghasmoved = false;
  whiterookkingsidehasmoved = false;
  whiterookqueensidehasmoved = false;

  blackkinghasmoved = false;
  blackrookkingsidehasmoved = false;
  blackrookqueensidehasmoved = false;

  enpassanttarget = -1;
  whiteTurn = true;
  selectedsquare = -1;
}

void setup() {
  FastLED.addLeds<WS2812B, ledPin, GRB>(
      leds,
      numLEDs
  );

  pinMode(latchPin, OUTPUT);
  pinMode(clockPin, OUTPUT);
  pinMode(dataPin, INPUT);

  Serial.begin(115200);

  FastLED.setBrightness(50);
  FastLED.clear();
  FastLED.show();

  calibratesensors();
  initializeboard();
}

void loop() {
  checkformove();
  updateleds();
  FastLED.show();

  delay(50);
}

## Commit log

2026-08-23 Added files for smarrt chess board
    [Chess Board.3mf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]
2026-08-23 Removed files
    [Chess board-B_Cu.gbr, Chess board-B_Mask.gbr, Chess board-B_Paste.gbr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]
2026-08-24 Update README with project details and status
    Added detailed project description, current status, features, hardware components, repository structure, assembly instructions, future plans, and libraries/tools used.
2026-08-27 Update README with budget and assembly details
    Added budget and SMT assembly notes to the README.
2026-08-27 Add BOM CSV file with itemized costs
    [bom.csv]
2026-08-27 Add project renders and schematics to README
    Added project renders and schematics section with images.
2026-09-02 Update BOM with new items and links
    [bom.csv]
2026-09-02 Update BOM with new items and adjust totals
    [bom.csv]
